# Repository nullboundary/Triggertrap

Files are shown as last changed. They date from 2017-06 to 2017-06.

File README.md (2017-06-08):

# Triggertrap Source Code

Triggertrap is an open-source camera triggering platform based on Arduino. 

It comes in two versions: Triggertrap v1 (TTv1), which is a device aimed at consumers; and Triggertrap Shield for Arduino (TT-k) which is aimed at advanced users, hackers, and geeks (like us!). 

The codebase you are looking at is for both the above devices. 

_NOTE_ - there *are* differences between the TTv1 and TT-k. By default, the code ships for the Triggertrap Shield for Arduino (TT-k), because we anticipate that most people downloading and using this code will be using the Triggertrap Shield. If you wish to compile and install this code on your TTv1 device, remember to go into TTConfig.h, and read the section *Choose your version of the Triggertrap*. 

## Triggertrap v1 (TTv1)

The Triggertrap v1 is a battery-powered device with several sensors built-in:

* Laser sensor
* Ambient Light sensor
* Sound sensor

It also has a fully configurable AUX port, in the shape of a RCA socket, designed to accept additional external inputs and sensors. 

_Form Factor_ - The Triggertrap v1 comes in a perspex casing, and uses touch-sensitive buttons for control and operation. 

## Triggertrap Shield for Arduino (TT-k)

The Triggertrap Shield for Arduino is an Arduino-powered device with several sensors built-in:

* Laser sensor
* Ambient Light sensor
* Sound sensor

It also has a fully configurable AUX port, in the shape of a RCA socket, designed to accept additional external inputs and sensors. 

_Form Factor_ - The Triggertrap Shield for Arduino is an Arduino shield, and uses physical buttons for its interface. 

# Open Source & Licencing information 

This file is part of Triggertrap. See Triggertrap.com for more information.

Triggertrap is free software: you can redistribute it and/or modify it under the terms of the GNU General Public License as published by the Free Software Foundation, either version 3 of the License, or (at your option) any later version.
 
Triggertrap is distributed in the hope that it will be useful, but WITHOUT ANY WARRANTY; without even the implied warranty of MERCHANTABILITY or FITNESS FOR A PARTICULAR PURPOSE.  See the GNU General Public License for more details.

You should have received a copy of the GNU General Public License along with Triggertrap. If not, see <http://www.gnu.org/licenses/>.

## Restrictions

The only thing we are keeping control over is the Triggertrap trademarks (name and logo). Full details of the Triggertrap licence is available on http://triggertrap.com/license/ 

# Changenotes

## 0.3.36 (6 March 2013)
* Bugfix: IR signal overflow fix for Nikon cameras when using shield only.
* Bugfix: Adjustment to IR timings for Sony cameras.
* Enhancement: Integration of Timelapse modifications from Duane Cassone. 

## 0.3.35 (16 July 2012)

* Bugfix: Fixes a tiny bug where the screen contrast (menu option added in 0.3.35) wasn't saved to EEPROM properly. 
* Bugfix: Elegant little hack that reads the LCD contrast setting twice, discarding the first reading, ensuring that the readings are accurate, especially when Triggertrap wakes from sleep. 
* Tagging with 0.3.35

## 0.3.34 (9 July 2012)

* Formally introduces Bulb Ramping into the Triggertrap Firmware
* Adds a menu item for adjusting your screen contrast for TTv1 (System -> Contrast)
* Bugfix: Fixes sleep problem introduced in 0.3.33b
* Tidies up code in TriggerTrap.cpp for easier hackability & readability

## 0.3.33b (18 June 2012)

* Introduces the Bulb Ramping feature
* Breaks several other features ;) (that is why this version was only ever a beta...)

## 0.3.32 (23 March 2012)

* Fixes a bug in the production Triggertrap where the laser sensor was too sensitive
* Fixes a bug in the production Triggertrap where the LCD display came up way too dark
* Adds additional documentation licence information that was missed out in the initial release
* Removes accidentally included .DS_Store files

## 0.3.31 (21 March 2012)

First open-source release of the Triggertrap codebase.

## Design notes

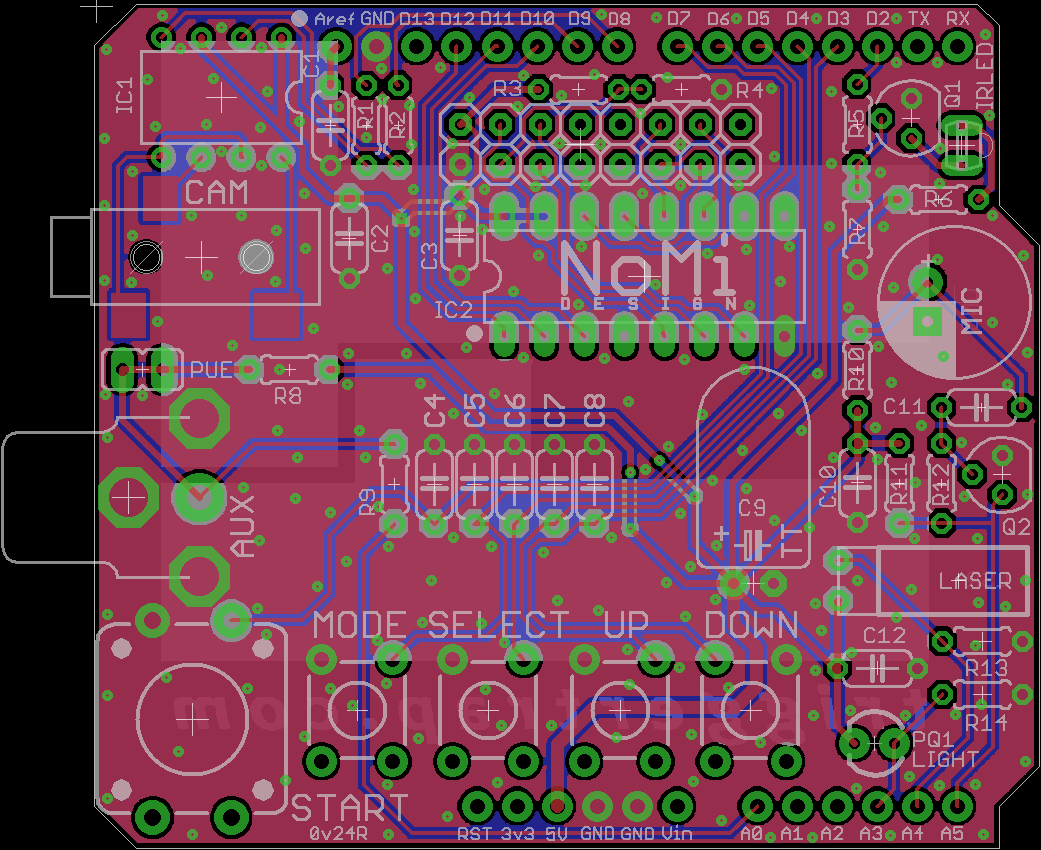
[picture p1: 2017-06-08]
Board Schematics/TT Shield for Arduino schematics v39/TriggerTrap Shield 0v24 Release.brd.png

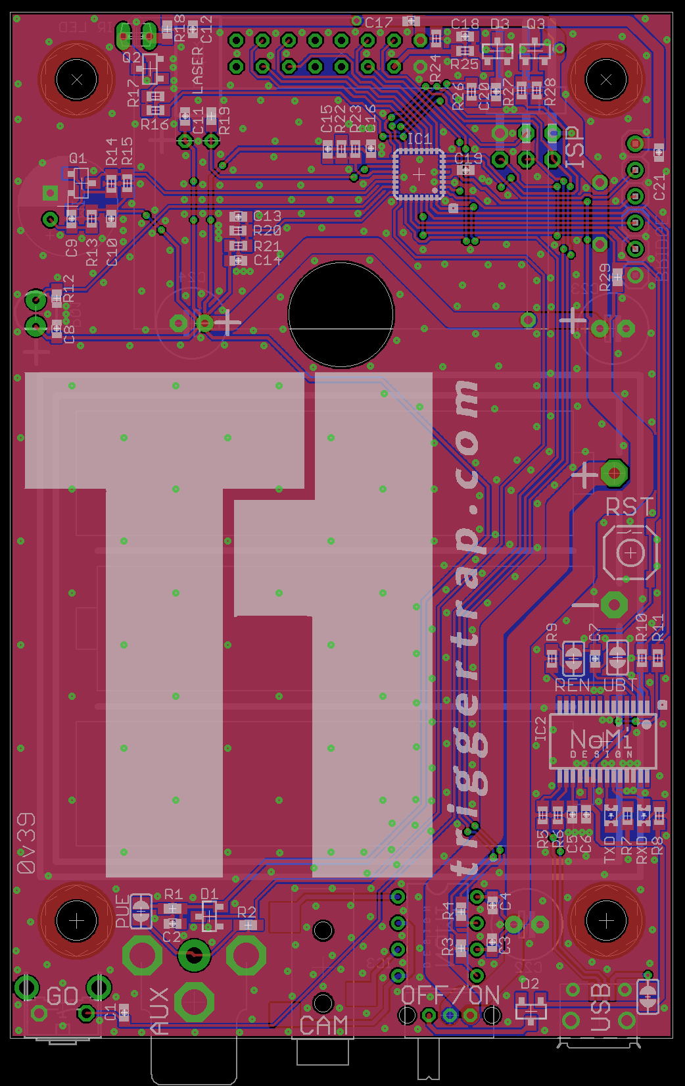
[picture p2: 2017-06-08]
Board Schematics/TTv1 schematics v39/TriggerTrap MainBoard 0v39 Release.brd.fill.png

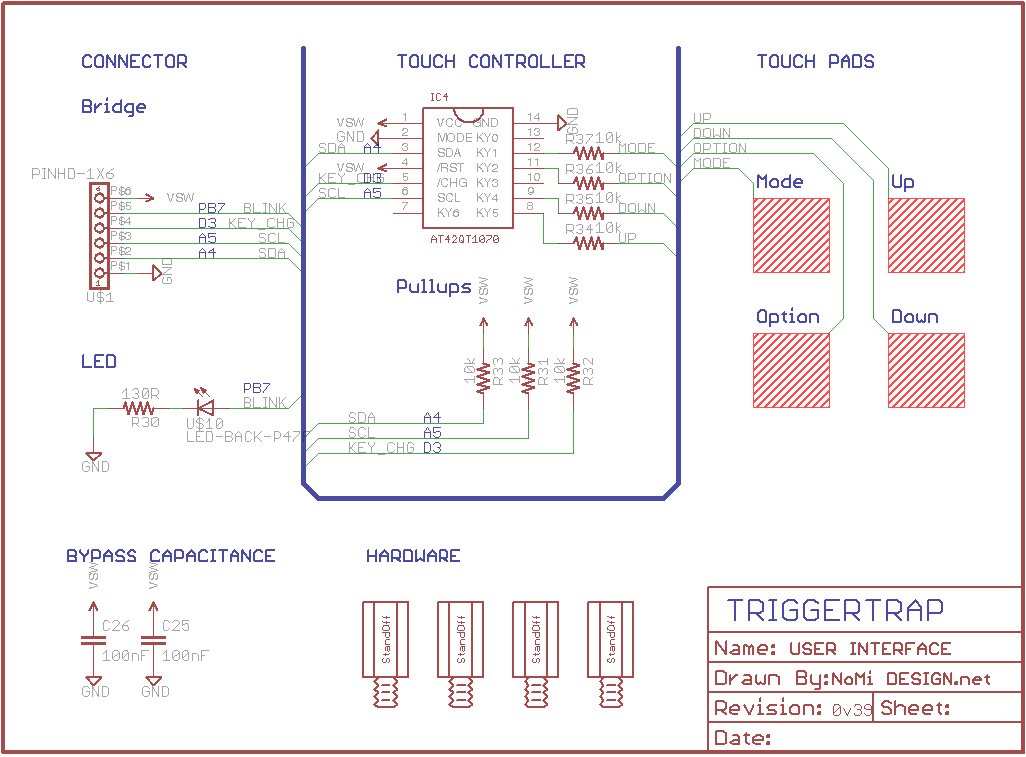
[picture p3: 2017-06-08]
Board Schematics/TTv1 schematics v39/TriggerTrap User Interface 0v39 Release.sch.png

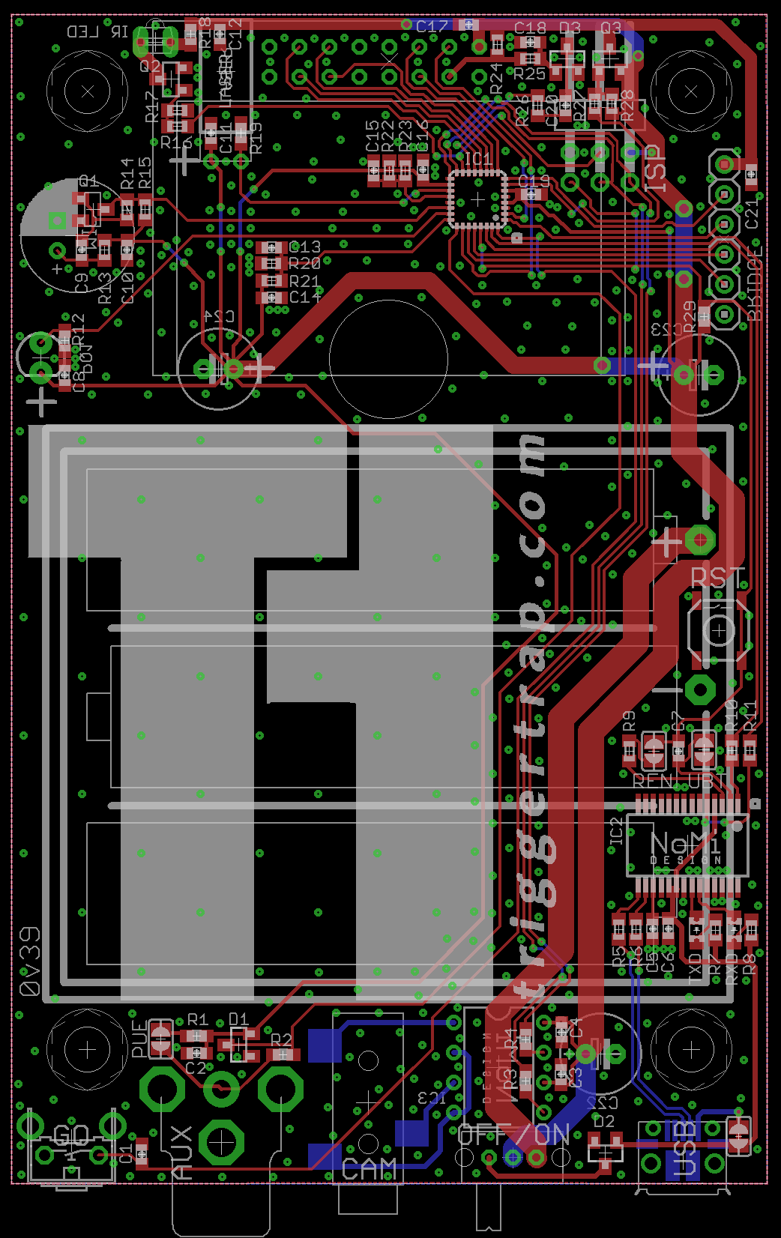
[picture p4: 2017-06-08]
Board Schematics/TTv1 schematics v39/TriggerTrap MainBoard 0v39 Release.brd.clear.png

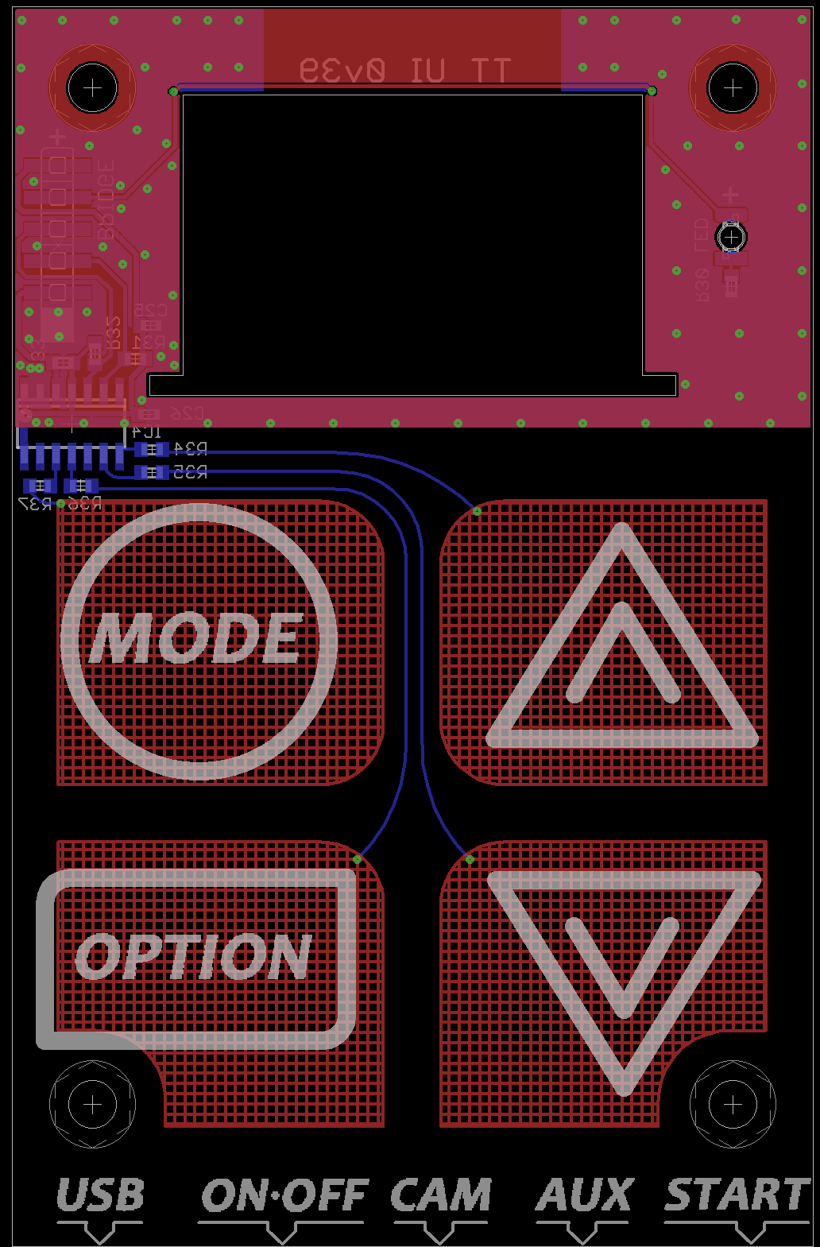
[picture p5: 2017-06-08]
Board Schematics/TTv1 schematics v39/TriggerTrap User Interface 0v39 Release.brd.png

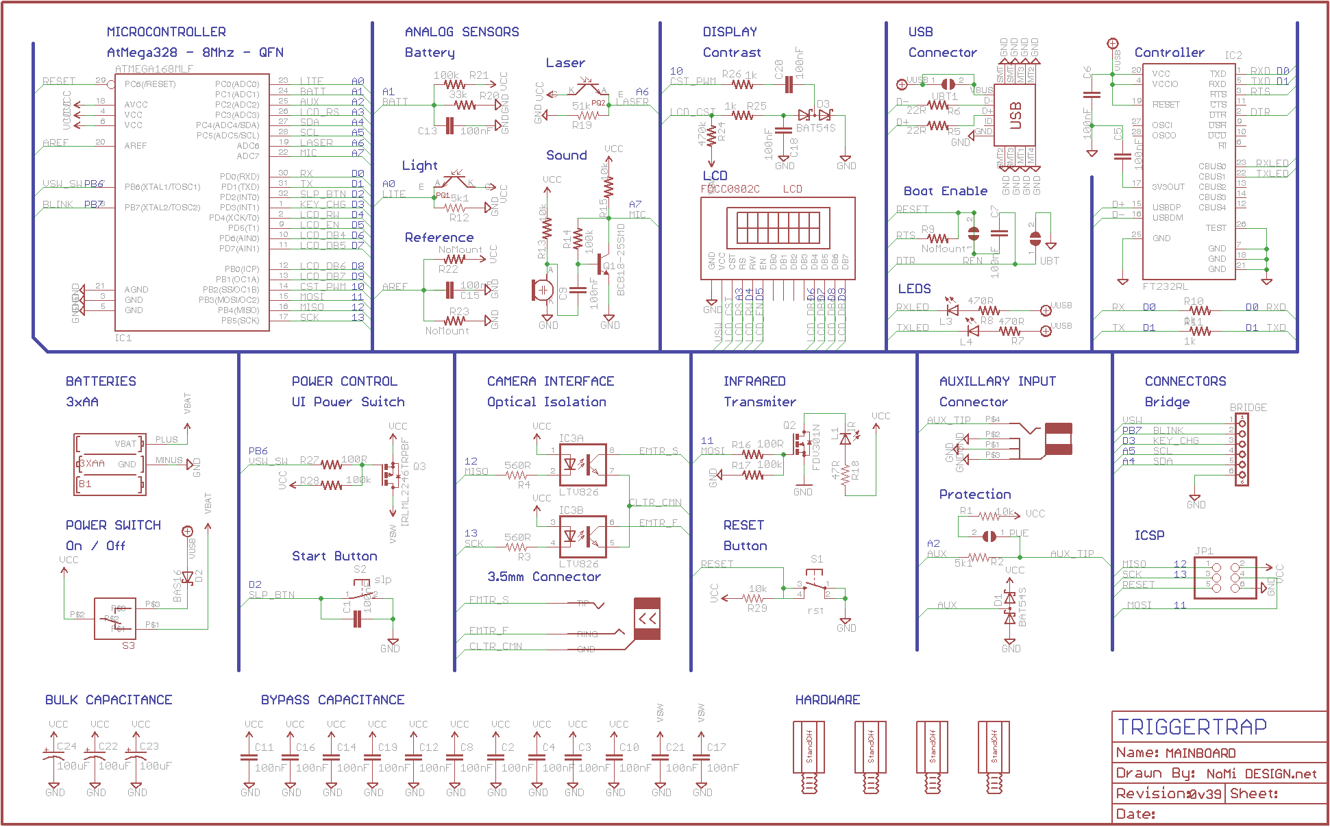
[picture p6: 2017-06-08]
Board Schematics/TTv1 schematics v39/TriggerTrap MainBoard 0v39 Release.sch.png

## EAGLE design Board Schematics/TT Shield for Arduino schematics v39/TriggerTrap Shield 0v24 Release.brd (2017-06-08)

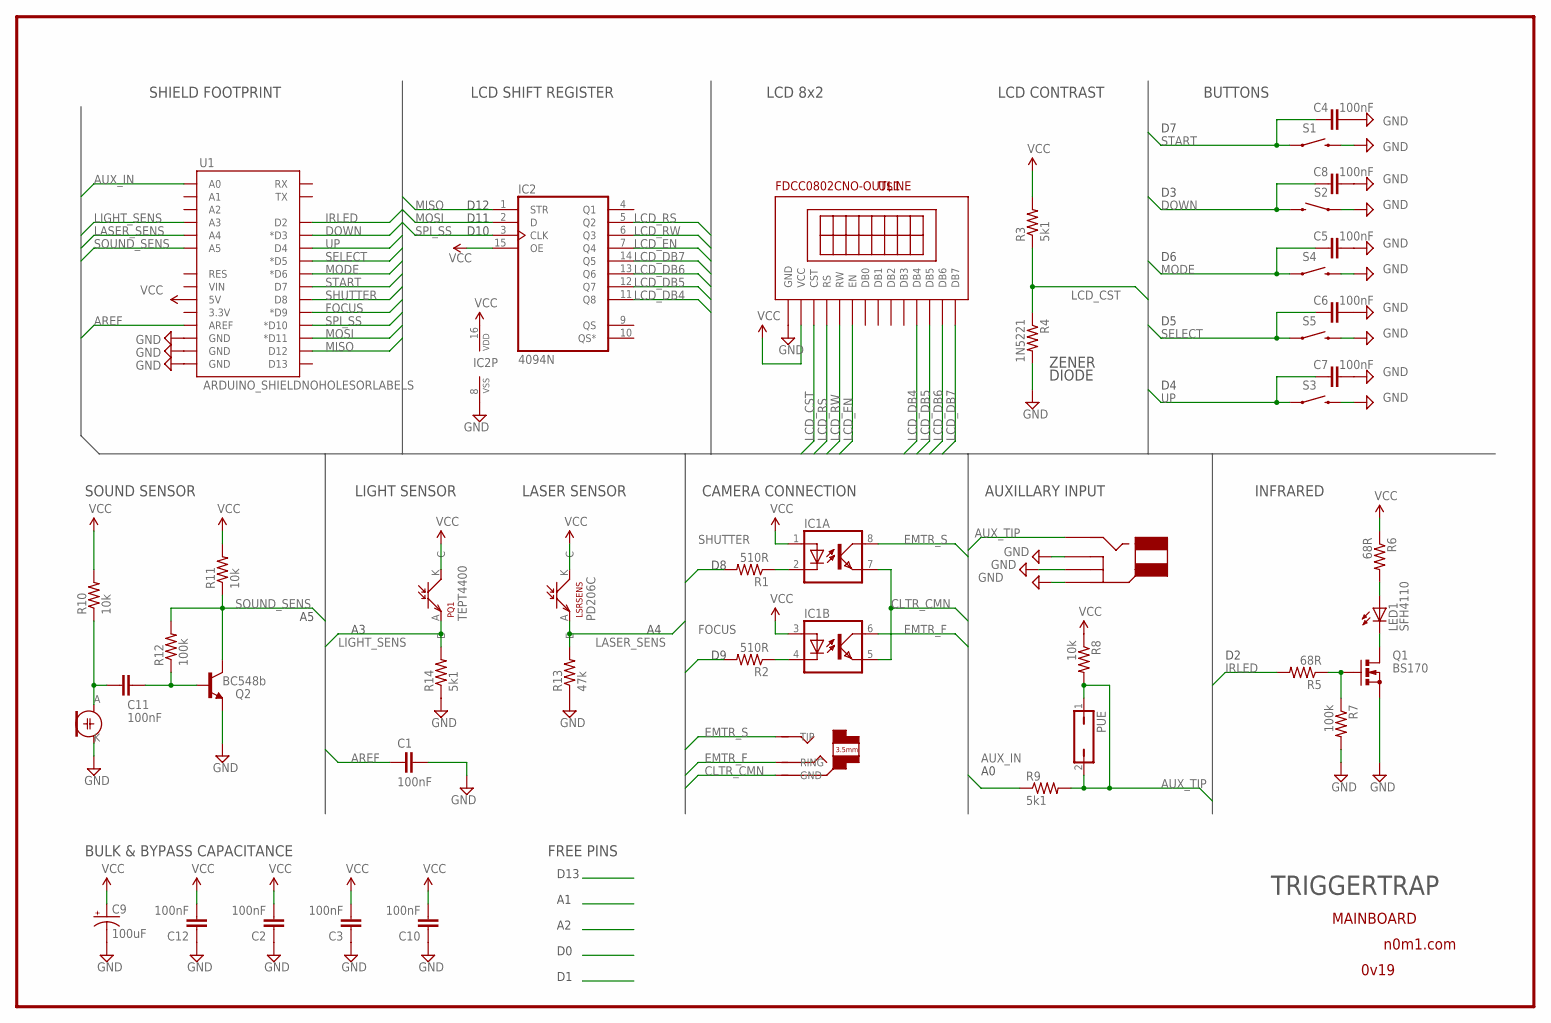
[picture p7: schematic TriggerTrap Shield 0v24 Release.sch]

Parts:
AUX: CUI_RCJ-017-RCA; RCA_CUI_RCJ-017
C1, C2, C3, C4, C5, C6, C7, C8, C10, C11, C12: 100nF; C050-024X044
C9: 100uF; TT2D7L
CAM: AUDIO_3.5MM_L_3523; AUDIO_3.5MM_LONG
IC1: LTV826SMLPADS; DIL08-SMLPADS
IC2: 4094N; DIL16
LED1: SFH4110; SIDE_LED
LSRSENS: PD204-6C; LSR-SNS-3MM
MIC: MIC; MIC-254-ECM94-RO
PQ1: TEPT4400; LED-3MM
PUE: JP1Q; JP1
Q1: BS170; SOT54E
Q2: BC548b; SOT54E
R1, R2: 510R; 0204/5
R3, R9, R14: 5k1; 0204/5
R4: 1N5221; 0204/5
R5, R6: 68R; 0204/5
R7, R12: 100k; 0204/5
R8, R10, R11: 10k; 0204/5
R13: 47k; 0204/5
S1: SWITCH-MOMENTARY-212MM; TACTILE-PTH-12MM
S2, S3, S4, S5: SWITCH-MOMENTARY-2PTH; TACTILE-PTH
U1: ARDUINO_SHIELDNOHOLESORLABELS; DUEMILANOVE_SHIELD_NOHOLES_NOLABELS
U$1: FDCC0802CNO-OUTLINE; 8X2-TOPLCD-NOOUTLINE

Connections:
AREF: C1.2, U1.AREF
AUX_IN: R9.1, U1.A0
AUX_TIP: AUX.P$4 (TIP), PUE.1, PUE.2, R8.2, R9.2
CLTR_CMN: CAM.P$1 (GND), IC1.5 (EMIT), IC1.7 (EMIT)
DOWN: C8.1, S2.3 (2), U1.D3 (*D3)
EMTR_F: CAM.P$3 (RING), IC1.6 (COL)
EMTR_S: CAM.P$2 (TIP), IC1.8 (COL)
FOCUS: R2.2, U1.D9 (*D9)
GND: AUX.P$1 (GND1), AUX.P$2 (GND2), AUX.P$3 (GND), C1.1, C2.1, C3.1, C4.2, C5.2, C6.2, C7.2, C8.2, C9.-, C10.1, C12.1, IC2.8 (VSS), MIC.K, Q1.S, Q2.S (E), R4.2, R7.2, R13.1, R14.1, S1.3 (2), S2.1, S3.3 (2), S4.3 (2), S5.3 (2), U1.GND@0 (GND), U1.GND@1 (GND), U1.GND@2 (GND), U$1.P$1 (GND)
IRLED: R5.2, U1.D2
LASER_SENS: LSRSENS.A (E), R13.2, U1.A4
LCD_CST: R3.1, R4.1, U$1.P$3 (CST)
LCD_DB4: IC2.11 (Q8), U$1.P$11 (DB4)
LCD_DB5: IC2.12 (Q7), U$1.P$12 (DB5)
LCD_DB6: IC2.13 (Q6), U$1.P$13 (DB6)
LCD_DB7: IC2.14 (Q5), U$1.P$14 (DB7)
LCD_EN: IC2.7 (Q4), U$1.P$6 (EN)
LCD_RS: IC2.5 (Q2), U$1.P$4 (RS)
LCD_RW: IC2.6 (Q3), U$1.P$5 (RW)
LIGHT_SENS: PQ1.A (E), R14.2, U1.A3
MISO: IC2.1 (STR), U1.D12
MODE: C5.1, S4.1, U1.D6 (*D6)
MOSI: IC2.2 (D), U1.D11 (*D11)
unnamed: C11.1, MIC.A, R10.1
unnamed: LED1.K (C), Q1.D
unnamed: LED1.A, R6.2
unnamed: Q1.G, R5.1, R7.1
unnamed: C11.2, Q2.G (B), R12.1
unnamed: IC1.4 (C), R2.1
unnamed: IC1.2 (C), R1.1
SELECT: C6.1, S5.1, U1.D5 (*D5)
SHUTTER: R1.2, U1.D8
SOUND_SENS: Q2.D (C), R11.1, R12.2, U1.A5
SPI_SS: IC2.3 (CLK), U1.D10 (*D10)
START: C4.1, S1.1, U1.D7
UP: C7.1, S3.1, U1.D4
VCC: C2.2, C3.2, C9.+, C10.2, C12.2, IC1.1 (A), IC1.3 (A), IC2.15 (OE), IC2.16 (VDD), LSRSENS.K (C), PQ1.K (C), R3.2, R6.1, R8.1, R10.2, R11.2, U1.5V, U$1.P$2 (VCC)

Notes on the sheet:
BULK & BYPASS CAPACITANCE
CAMERA CONNECTION
INFRARED
AUXILLARY INPUT
TRIGGERTRAP
MAINBOARD
n0m1.com
0v19
D10
D11
D12
SHIELD FOOTPRINT
LCD 8x2
LCD CONTRAST
LCD SHIFT REGISTER
SOUND SENSOR
LASER SENSOR
LIGHT SENSOR
BUTTONS
FREE PINS
D13
ZENER
DIODE
TEPT4400
PD206C

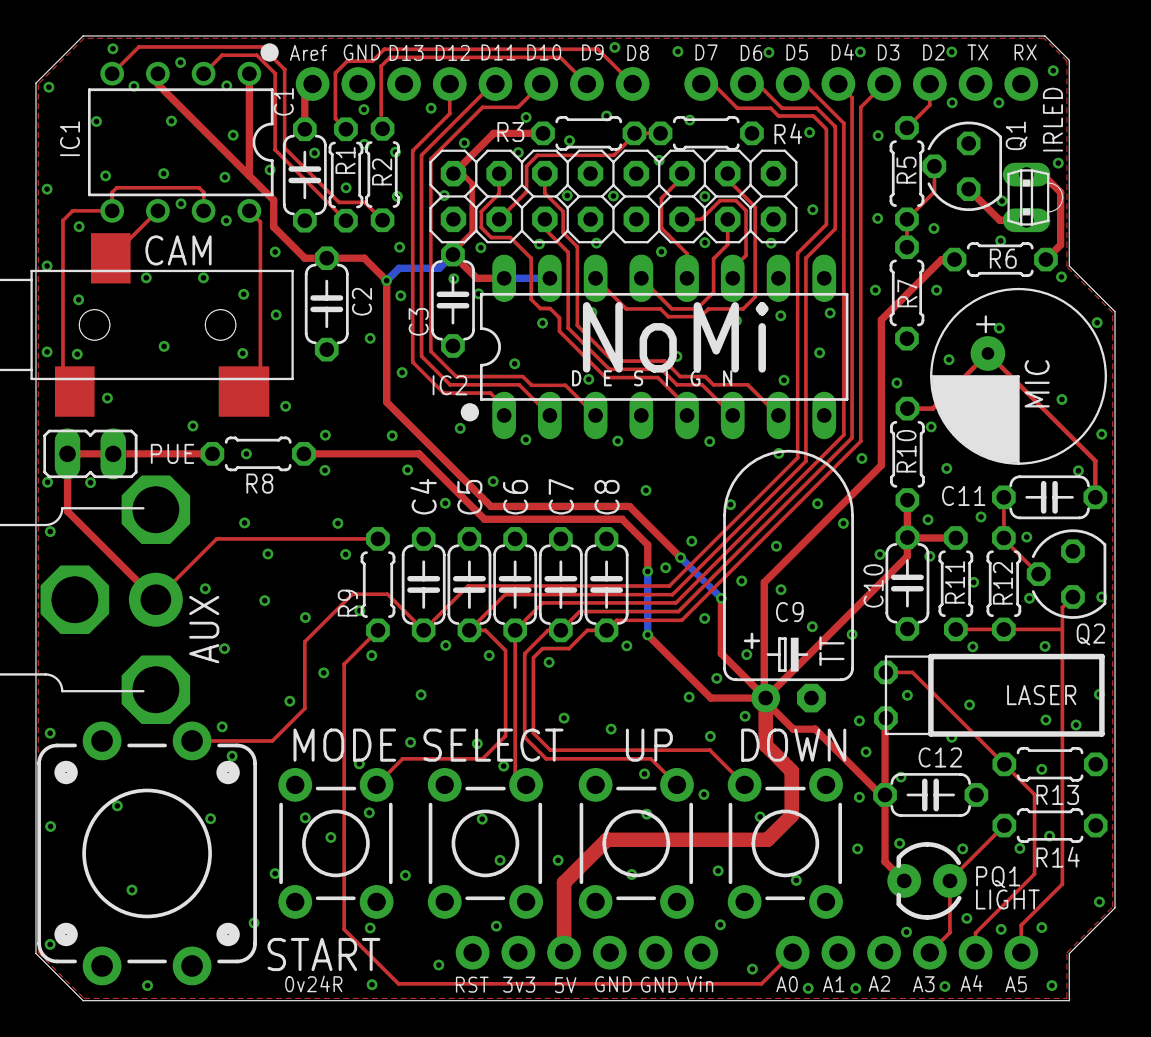
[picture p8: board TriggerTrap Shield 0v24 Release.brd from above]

Board: 2 copper layers, 59.9 x 53.6 mm, 44 parts (1 on the bottom side), 37 nets.

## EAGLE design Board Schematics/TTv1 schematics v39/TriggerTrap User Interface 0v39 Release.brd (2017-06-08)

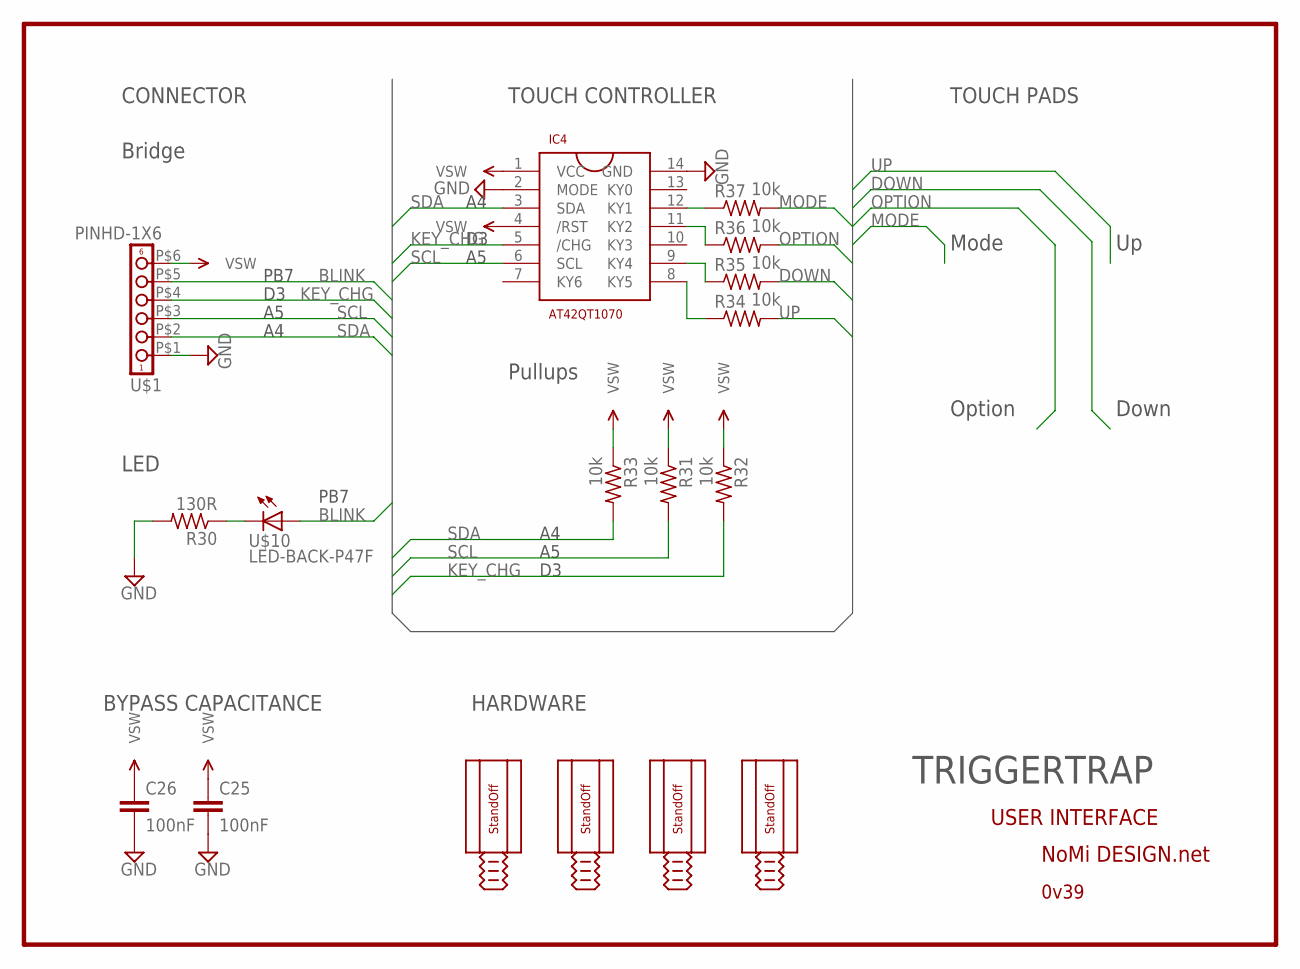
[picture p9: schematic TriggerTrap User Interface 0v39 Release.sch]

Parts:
C25, C26: 100nF; C0603K
IC4: AT42QT1070; 14SOIC
R30: 130R; R0603
R31, R32, R33, R34, R35, R36, R37: 10k; R0603
U$1: PINHD-1X6; PINHD-1X6-SMD
U$2, U$23, U$24, U$25: STAND-0FF-3.2; STAND-OFF
U$10: LED-BACK-P47F; LED-P47F

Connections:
BLINK: U$1.P$5 (5), U$10.A
DOWN: R35.2
GND: C25.2, C26.2, IC4.2 (MODE), IC4.14 (GND), R30.2, U$1.P$1 (1)
KEY_CHG: IC4.5 (/CHG), R32.2, U$1.P$4 (4)
MODE: R37.2
unnamed: IC4.12 (KY1), R37.1
unnamed: IC4.11 (KY2), R36.1
unnamed: IC4.9 (KY4), R35.1
unnamed: IC4.8 (KY5), R34.1
unnamed: R30.1, U$10.C
OPTION: R36.2
SCL: IC4.6 (SCL), R31.2, U$1.P$3 (3)
SDA: IC4.3 (SDA), R33.2, U$1.P$2 (2)
UP: R34.2
VSW: C25.1, C26.1, IC4.1 (VCC), IC4.4 (/RST), R31.1, R32.1, R33.1, U$1.P$6 (6)

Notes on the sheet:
Bridge
HARDWARE
BYPASS CAPACITANCE
TOUCH CONTROLLER
LED
TRIGGERTRAP
USER INTERFACE
NoMi DESIGN.net
0v39
PB7
CONNECTOR
TOUCH PADS
Mode
Down
Option
Pullups

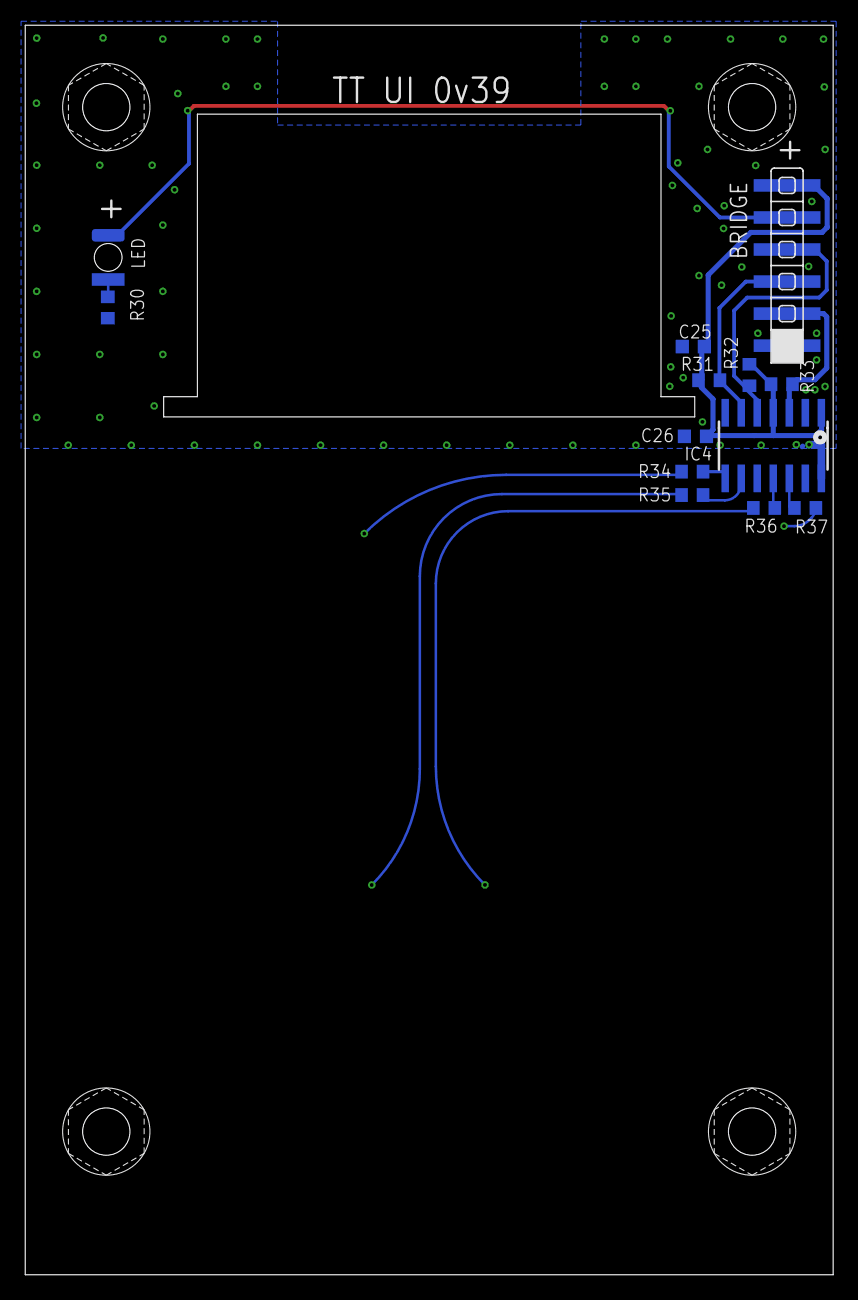
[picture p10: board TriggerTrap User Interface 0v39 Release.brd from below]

Board: 2 copper layers, 64.0 x 99.0 mm, 17 parts (17 on the bottom side), 11 nets.

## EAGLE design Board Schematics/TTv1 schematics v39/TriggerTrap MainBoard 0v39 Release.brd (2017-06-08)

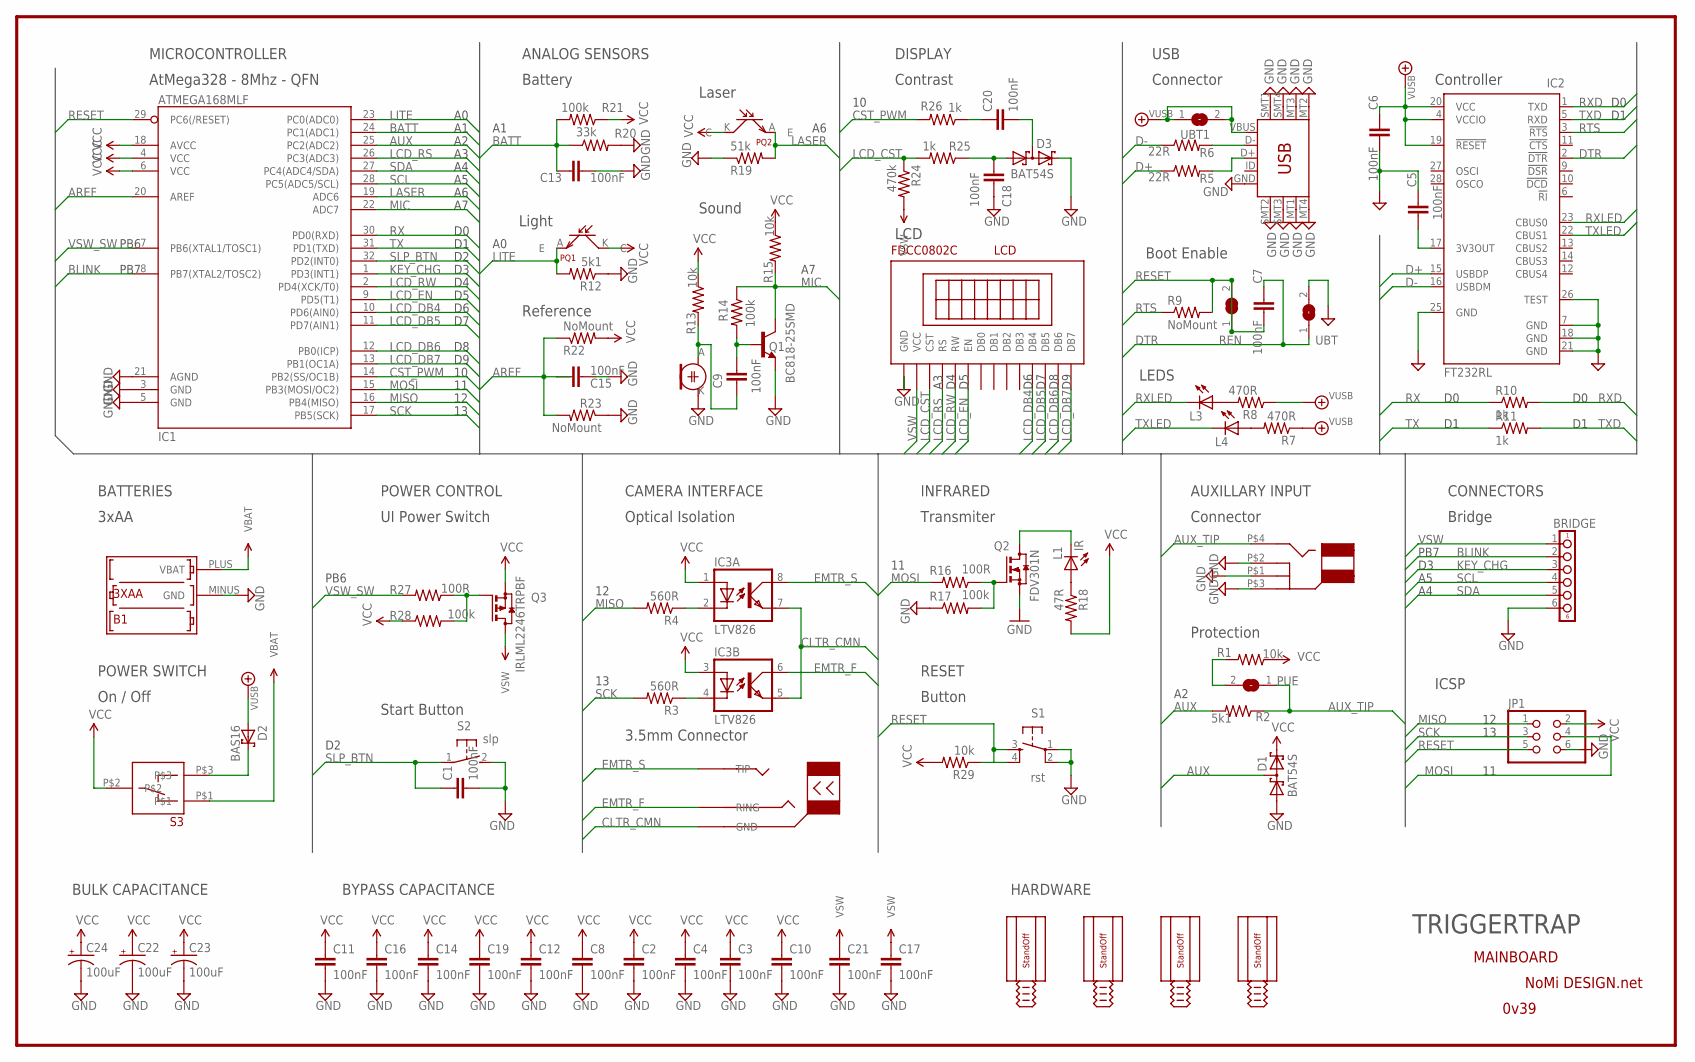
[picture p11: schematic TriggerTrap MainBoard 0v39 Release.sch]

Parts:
AUXJACK: CUI_RCJ-017-RCA; RCA_CUI_RCJ-017
B1: 3XAA; 3XAA-CASE
BRIDGE: PINHD-1X6; 1X06
C1, C2, C3, C4, C5, C6, C7, C8, C9, C10, C11, C12, C13, C14, C15, C16, C17, C18, C19, C20, C21: 100nF; 0603-CAP
C22, C23, C24: 100uF; E2,5-7
CAMJACK: AUDIO_3.5MM_L_3523; AUDIO_3.5MM_LONG
D1, D3: BAT54S; SOT23
D2: BAS16; SOT23
IC1: ATMEGA168MLF; MLF32
IC2: FT232RL; SSOP28
IC3: LTV826; DIL08R
JP1: PINHD-2X3/90; 2X03/90
L1: IR; SIDE_LED
L3, L4: LEDCHIPLED_0805; CHIPLED_0805
LCD: FDCC0802C; 8X2-TOPLCD
M1: 254-ECM94-RO; MIC-254-ECM94-RO
PQ1: TEPT4400; LED-3MM
PQ2: EL-PT204-6C; LSR-SNS-3MM
PUE: SJ
Q1: BC818-25SMD; SOT23-BEC
Q2: FDV301N; SOT23
Q3: IRLML2246TRPBF; SOT23
R1, R29: 10k; 0603-RES
R2, R12: 5k1; 0603-RES
R3, R4: 560R; 0603-RES
R5, R6: 22R; R0603
R7, R8: 470R; R0603
R9, R22, R23: NoMount; R0603
R10, R11, R25, R26: 1k; R0603
R13, R15: 10k; R0603
R14, R17, R21, R28: 100k; R0603
R16, R27: 100R; R0603
R18: 47R; 0603-RES
R19: 51k; 0603-RES
R20: 33k; R0603
R24: 470k; R0603
REN: SJ
S1: rst; TACTILE_SWITCH_SMD
S2: slp; B3F-31XX
S3: OS102011MA1QN1
U$2, U$23, U$24, U$25: STAND-0FF-3.2; STAND-OFF
UBT, UBT1: SJ
USB: USB-MICRO-B-SMD; USB-MICROB-SMD

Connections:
AREF: C15.1, IC1.20 (AREF), R22.1, R23.2
AUX: D1.3 (C1A2), IC1.25 (PC2(ADC2)), R2.2
AUX_TIP: AUXJACK.P$4 (TIP), PUE.1, R2.1
BATT: C13.1, IC1.24 (PC1(ADC1)), R20.1, R21.2
BLINK: BRIDGE.2, IC1.8 (PB7(XTAL2/TOSC2))
CLTR_CMN: CAMJACK.P$1 (GND), IC3.5 (EMIT), IC3.7 (EMIT)
CST_PWM: IC1.14 (PB2(SS/OC1B)), R26.2
D+: IC2.15 (USBDP), R5.1
D-: IC2.16 (USBDM), R6.1
DTR: C7.1, IC2.2 (!DTR), UBT.1
EMTR_F: CAMJACK.P$3 (RING), IC3.6 (COL)
EMTR_S: CAMJACK.P$2 (TIP), IC3.8 (COL)
GND: AUXJACK.P$1 (GND1), AUXJACK.P$2 (GND2), AUXJACK.P$3 (GND), B1.MINUS (GND), BRIDGE.6, C1.2, C2.2, C3.2, C4.2, C5.1, C6.2, C8.2, C10.2, C11.2, C12.2, C13.2, C14.2, C15.2, C16.2, C17.2, C18.1, C19.2, C21.2, C22.-, C23.-, C24.-, D1.1 (A1), D3.2 (C2), IC1.3 (GND), IC1.5 (GND), IC1.21 (AGND), IC2.7 (GND), IC2.18 (GND), IC2.21 (GND), IC2.25 (GND), IC2.26 (TEST), JP1.6, LCD.P$1 (GND), M1.K, Q1.E, Q2.2 (S), R12.1, R17.1, R19.1, R20.2, R23.1, S1.1, S1.2, S2.2 (S), UBT.2, USB.GND, USB.MT1 (MTN1), USB.MT2 (MTN2), USB.MT3 (MTN3), USB.MT4 (MTN4), USB.SMT1, USB.SMT2, USB.SMT3, USB.SMT4
KEY_CHG: BRIDGE.3, IC1.1 (PD3(INT1))
LASER: IC1.19 (ADC6), PQ2.A (E), R19.2
LCD_CST: LCD.P$3 (CST), R24.1, R25.2
LCD_DB4: IC1.10 (PD6(AIN0)), LCD.P$11 (DB4)
LCD_DB5: IC1.11 (PD7(AIN1)), LCD.P$12 (DB5)
LCD_DB6: IC1.12 (PB0(ICP)), LCD.P$13 (DB6)
LCD_DB7: IC1.13 (PB1(OC1A)), LCD.P$14 (DB7)
LCD_EN: IC1.9 (PD5(T1)), LCD.P$6 (EN)
LCD_RS: IC1.26 (PC3(ADC3)), LCD.P$4 (RS)
LCD_RW: IC1.2 (PD4(XCK/T0)), LCD.P$5 (RW)
LITE: IC1.23 (PC0(ADC0)), PQ1.A (E), R12.2
MIC: IC1.22 (ADC7), Q1.C, R14.1, R15.2
MISO: IC1.16 (PB4(MISO)), JP1.1, R4.2
MOSI: IC1.15 (PB3(MOSI/OC2)), JP1.4, R16.2
unnamed: C9.1, M1.A, R13.2
unnamed: L1.K (C), Q2.3 (D)
unnamed: C20.1, R26.1
unnamed: L1.A, R18.1
unnamed: C20.2, D3.3 (C1A2)
unnamed: D2.3 (C), S3.P$3
unnamed: Q2.1 (G), R16.1, R17.2
unnamed: L3.A, R8.2
unnamed: L4.A, R7.2
unnamed: C9.2, Q1.B, R14.2
unnamed: IC3.4 (C), R3.1
unnamed: Q3.1 (G), R27.1, R28.2
unnamed: IC3.2 (C), R4.1
unnamed: C18.2, D3.1 (A1), R25.1
unnamed: PUE.2, R1.2
unnamed: C5.2, IC2.17 (3V3OUT)
unnamed: R6.2, USB.D-
unnamed: R5.2, USB.D+
RESET: C7.2, IC1.29 (PC6(/RESET)), JP1.5, R9.2, R29.1, REN.1, REN.2, S1.3, S1.4
RTS: IC2.3 (!RTS), R9.1
RX: IC1.30 (PD0(RXD)), R10.1
RXD: IC2.1 (TXD), R10.2
RXLED: IC2.23 (CBUS0), L3.C
SCK: IC1.17 (PB5(SCK)), JP1.3, R3.2
SCL: BRIDGE.4, IC1.28 (PC5(ADC5/SCL))
SDA: BRIDGE.5, IC1.27 (PC4(ADC4/SDA))
SLP_BTN: C1.1, IC1.32 (PD2(INT0)), S2.1
TX: IC1.31 (PD1(TXD)), R11.1
TXD: IC2.5 (RXD), R11.2
TXLED: IC2.22 (CBUS1), L4.C
VBAT: B1.PLUS (VBAT), S3.P$1
VCC: C2.1, C3.1, C4.1, C8.1, C10.1, C11.1, C12.1, C14.1, C16.1, C19.1, C22.+, C23.+, C24.+, D1.2 (C2), IC1.4 (VCC), IC1.6 (VCC), IC1.18 (AVCC), IC3.1 (A), IC3.3 (A), JP1.2, PQ1.K (C), PQ2.K (C), Q3.2 (S), R1.1, R13.1, R15.1, R18.2, R21.1, R22.2, R28.1, R29.2, S3.P$2
VSW: BRIDGE.1, C17.1, C21.1, LCD.P$2 (VCC), Q3.3 (D), R24.2
VSW_SW: IC1.7 (PB6(XTAL1/TOSC1)), R27.2
VUSB: C6.1, D2.1 (A), IC2.4 (VCCIO), IC2.19 (!RESET), IC2.20 (VCC), R7.1, R8.1, UBT1.1, UBT1.2, USB.VBUS

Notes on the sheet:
MICROCONTROLLER
BATTERIES
BULK CAPACITANCE
POWER SWITCH
BYPASS CAPACITANCE
CAMERA INTERFACE
POWER CONTROL
ANALOG SENSORS
Sound
INFRARED
USB
Boot Enable
HARDWARE
RESET
AUXILLARY INPUT
ICSP
LEDS
CONNECTORS
TRIGGERTRAP
MAINBOARD
NoMi DESIGN.net
0v39
PB6
PB7
UI Power Switch
Start Button
Optical Isolation
3.5mm Connector
Battery
AtMega328 - 8Mhz - QFN
Reference
Transmiter
3xAA
On / Off
Laser
Light
Button
DISPLAY
Contrast
LCD

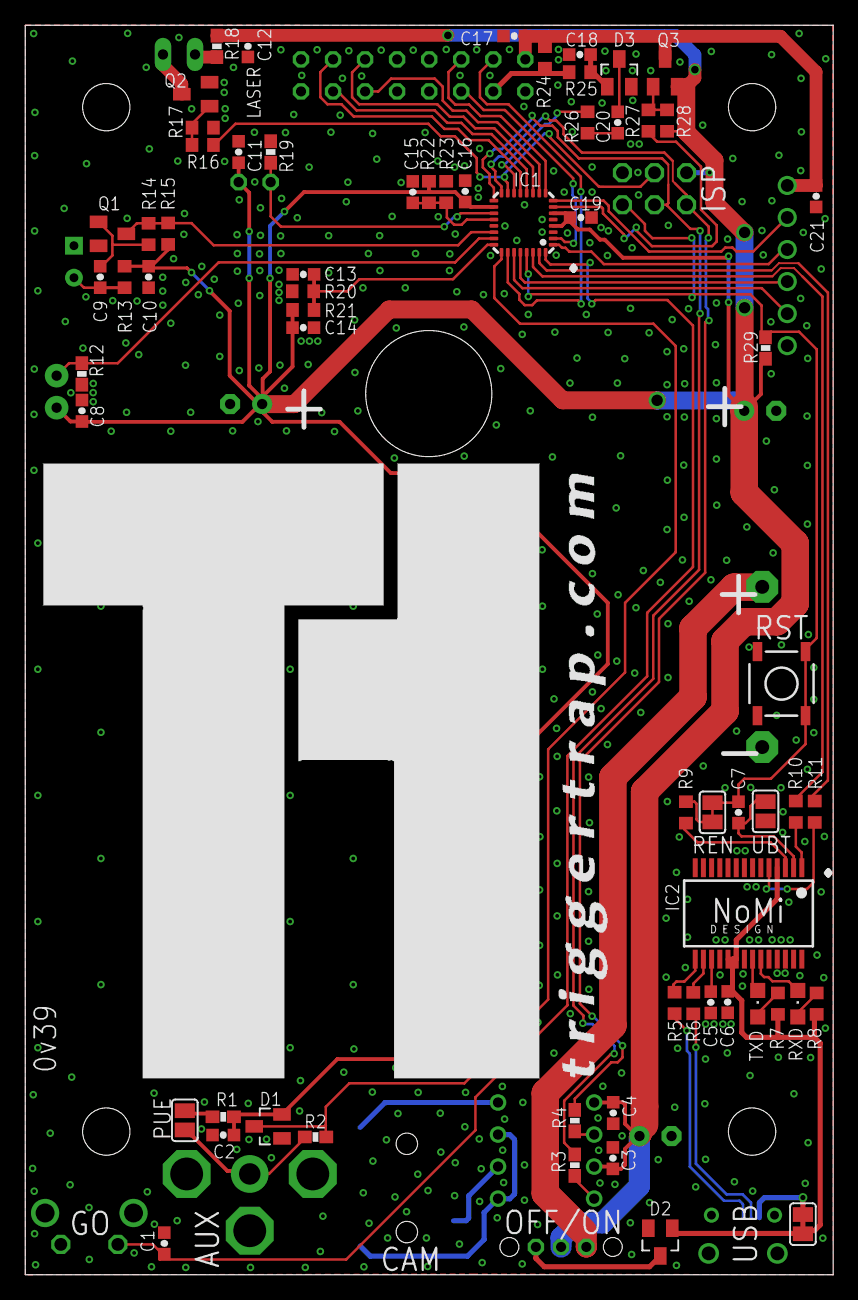
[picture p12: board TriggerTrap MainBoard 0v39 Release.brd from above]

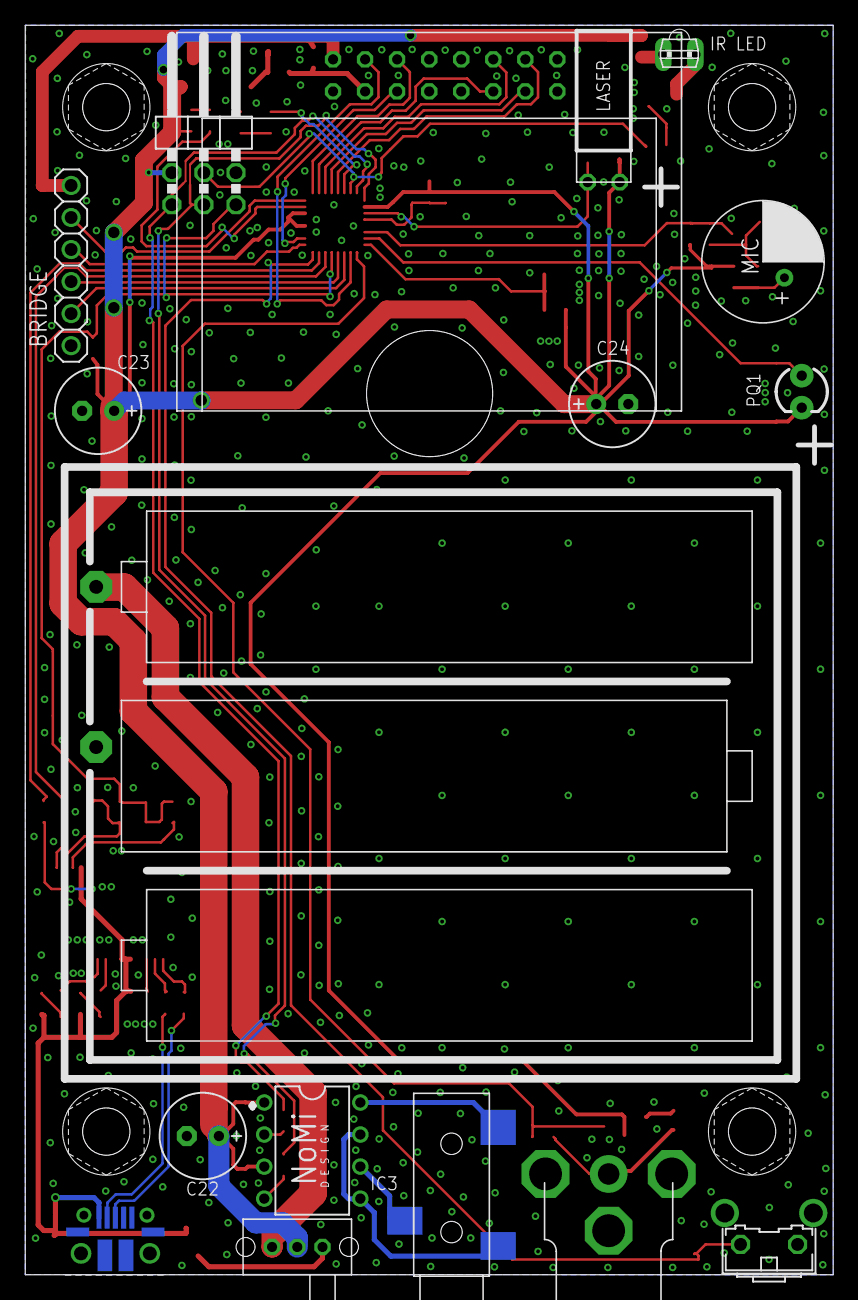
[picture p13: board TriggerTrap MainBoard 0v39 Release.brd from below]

Board: 2 copper layers, 64.0 x 99.0 mm, 86 parts (20 on the bottom side), 62 nets.

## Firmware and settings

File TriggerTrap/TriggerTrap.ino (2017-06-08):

/************************************************************************************
 * 	
 *      Name    : Triggertrap Arduino Sketch                         
 *      Author  : Noah Shibley   / NoMi Design - http://n0m1.com
 *              : Michael Grant  / NoMi Design - http://n0m1.com
 *              : Haje Jan Kamps / Triggertrap - http://triggertrap.com                        
 *      Updated : July 16, 2012                                    
 *      Version : 0.3.36                                              
 * 	Notes   : Triggertrap code for Triggertrap Device and Triggertrap Shield for Arduino. 
 *                For more information see Triggertrap.com and github.com/triggertrap
 * 
 *                Code for Triggertrap device (TTv1) and Triggertrap Shield (TT-k)                      
 * 
 *      Copyright (c) 2012 NoMi Design (http://n0m1.com) All right reserved.
 * 
 *      This file is part of Triggertrap. See Triggertrap.com for more information.
 * 
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
 ***********************************************************************************/

#include <I2C.h>
#include <PinChangeInt.h>
#include <PinChangeIntConfig.h>
#include <LCD.h>
#include <LiquidCrystal.h>
#include <LiquidCrystal_SR_LCD3.h>
#include <AtTouch.h>
#include <TTSleep.h>
#include <TriggerTrap.h>

const int LASER_MODE = 0;
const int SOUND_MODE = 1;
const int LIGHT_MODE = 2;
const int TIMELAPSE_MODE = 3; 
const int AUX_MODE = 4;


TriggerTrap tt;

/***********************************************************
 * 
 * Setup
 * 
 ***********************************************************/
void setup() {   

  tt.setup();

}

/***********************************************************
 * 
 * loop
 * 
 ***********************************************************/
void loop() {

  tt.update();
  
  if(tt.trigger())
  {
    
     if(tt.triggerMode() == SOUND_MODE)
     {
       //Serial.println("sound trigger");
     }
     else if(tt.triggerMode() == LASER_MODE)
     {
       //Serial.println("laser trigger");
     }  
     else if(tt.triggerMode() == LIGHT_MODE)
     {
       //Serial.println("light trigger");
     }  
     else if(tt.triggerMode() == TIMELAPSE_MODE)
     {
       //Serial.println("timelapse trigger");
     }   
     else if(tt.triggerMode() == AUX_MODE)
     {
       //Serial.println("aux trigger");
     }    
    
  }

}

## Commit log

2011-09-15 updates for 0v34 board
2011-09-16 LCD working, Touch Chip Reset, c style str concats
    LCD is now fully working, the TTUI library now extends Liquid Crystal
    Lib. Also AtTouch now resets the touch chip in the library begin()
    function. In case the mcu reset, but the touch chip did not. Delay time
    formatting now uses strcat instead of arduino String. Aux.h and cpp
    were changed to auxiliary.h and cpp because of crazy windows 7 not
    allowing files named aux.h !
2011-09-16 start button and UI power On/Off should be working
    UI power off works, and probably power ON. However my start button is
    not working…could be a hardware problem? Bad solder joint?
2011-09-19 Minor changes to LCD. Power on, and power off not working but errors are commented out
2011-09-19 Changed LCD menu formatting, and added threshold sensor level feedback
    Sensor level is not displayed on the LCD when you try to set the
    threshold. Its a little confusing, maybe we need to label the
    difference between sensor level and threshold setting. However this is
    not much space...
2011-09-21 Added feature to give feedback when Trigger is active. Also switched to LiquidCrystalFast library
    Should see LCD feedback when trap is active in USB power mode.
2011-09-27 Delay added to AtTouch Lib. Fixes the auto calibration time out.
2011-09-27 fixed TTSleep so wdt doesn't reset on timeout, instead it just interrupts
2011-09-27 Switched from Wire lib i2c lib by Wayne Truchsess.
2011-09-29 Eeprom settings values are now saved and restored. Also start button hold & reset is complete. MCU sleep for time-lapse is started but not complete.
2011-09-30 Added Michael's power up / power down code. bug fixes, and cleaning.
    Sleep currently won't wake up. Only in battery mode.
2011-11-09 fixed some issues related to the WatchDog sleep in the timelapse class.
    Should be working now, however the TT has trouble detecting "battery
    mode" so it doesn't switch into sleep mode
2011-11-10 Fixed time-lapse sleep for battery, it works except for the first shot, which sometimes has the wrong delta.
2011-11-14 Changed the sleep library to a totally new one based on the code by "Cloudy"
    written by "Cloudy" in this post
    http://www.arduino.cc/cgi-bin/yabb2/YaBB.pl?num=1292898715
2011-11-17 fixed, Camera trigger AB swap bug, small updates to delay lcd display, and IR control
2011-11-18 added millisecond delay. Created millisecond time formatting, updated menu text
2011-11-19 added separate shutter reset for A and B triggers, removed IRshutter for testing.
    Also made all the sensors trigger both A and B triggers
2011-11-23 small fix to laser trigger. Related to menus in menuOpts array
2011-11-24 added sensor read out refresh, and updated new TTIRremote library from michael.
2011-11-30 Major update. New shutter code, and button press behavior
    the new shutter code separates shutter,focus and IR into totally
    separate independent sections. The new button behavior shows you the
    previous press before updating
2011-12-03 Focus always fires now, just how long it fires changes, based on whether its on/off
    I also fixed a bug related to time-lapse sleep. Where the buttons
    wouldn't work for awhile after it wakes.
2011-12-16 TT Shield code added, TTConfig added, lots of restructuring
    There is a new interface class that is a middle layer between all TT
    stuff and your arduino sketch....should to make things cleaner.
2011-12-17 Small fix to the arduino sketch includes
    Weirdest bug ever, arduino ignores /* */ comment tags for the
    includes...
    [TriggerTrap.ino]
2012-01-29 New LCD lib for shield, plus fixes for shield buttons
    [TriggerTrap.ino]
2012-01-30 updated i2c lib to rev5, added firmware version number
2012-02-03 added interrupts for startbutton on TT Shield
2012-03-21 v0.3.31 - Initial open source release
    Here goes nothing… This is the first release of the Triggertrap
    codebase released under open source licence.
2012-03-23 bug fixes to laser and LCD for working with factory production model
2012-03-23 small bug fix to laser threshold setting
    [TriggerTrap.ino]
2012-03-30 Updating Config file to reflect new default behaviour
    The standard behaviour has changed: We now assume that people
    downloading the code are doing so because they want to run it on a
    Triggertrap Shield for Arduino. People who are developing on the TTv1,
    need to comment out the #define TT_SHIELD statement in the config file.
    This update amends the in-line help to reflect this change.
2012-06-20 Expanding explanation for Shield / TTv1 switch
2012-07-09 Triggertrap Firmware v0.3.34
    Adding Bulb Ramping & Contrast control + bugfixes
    [TriggerTrap.ino]
2012-07-16 Triggertrap v0.3.35
    Fixes a small bug where screen contrast readings were wrong after
    waking up from deep sleep.
    [TriggerTrap.ino]
2012-08-03 added boards file to create TriggerTrap V1.0 option in the arduino menu
2012-08-29 Correcting spelling of Triggertrap
    In the boards file, Triggertrap was spelled incorrectly - whoops.
2012-08-30 fixed case - important on Linux where files are case sensitive
2012-10-28 Update libraries/TriggerTrap/TTConfig.h
    Updated the reference to the laser sensor - was A3, should be A4.
2017-06-07 Commit schematics to Github
    schematics used to live on http://triggertrap.com/schematics, but as
    the site went down, the schematics went with them.
    [TriggerTrap MainBoard 0v39 Release.brd, TriggerTrap MainBoard 0v39 Release.sch, TriggerTrap Shield 0v24 Release.brd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]
